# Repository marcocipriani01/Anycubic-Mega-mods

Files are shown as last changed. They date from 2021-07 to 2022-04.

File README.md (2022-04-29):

# Anycubic Mega S mods

This is a collection of mods of the Anycubic Mega S 3D printer. Feel free to experiment with them!

## Copyright notice

This collection contains 3D models and configuration files made by different people (all released without license), and further modified by Marco Cipriani (@marcocipriani01). If you are the original author of one the models, and wish to remove it from this repository, feel free to open a GitHub issue to get in touch. I'm releasing all these modified files under the terms of the **GNU General Public License**, version 3.0. Modifying any of these 3D models requires you to publish them again, under the terms of the same license, and give credits to the original authors. In any way, shall the authors of these files be considered responsible for damages occurred to your 3D printer.

### Credits

- [Anycubic i3 Mega X carriage and Hemera mod](https://www.thingiverse.com/thing:4238185) by Sergiu-I
- ["Filler" filament spool holder](https://www.thingiverse.com/thing:3020026) by HugoHuge
- [BLShield](https://www.thingiverse.com/thing:3419174) by PrinterMods
- [Klipper configuration](https://github.com/widapro/3d-printers) by widapro
- [Customizable fan cover](https://www.thingiverse.com/thing:2802474) by mightynozzle
- [Anycubic I3 Mega feet](https://www.thingiverse.com/thing:3480829/files) by Alexis Rodriguez
- [Anycubic I3 Mega Hot Bed Handle](https://www.thingiverse.com/thing:3217199/files) by Andy Baxter
- [AnyCubic i3 Mega LCD Bezel](https://www.thingiverse.com/thing:2920401/files) by Rui Carneiro

## Other resources

- [Marlin 2.0.x for the Anycubic Mega](https://github.com/knutwurst/Marlin-2-0-x-Anycubic-i3-MEGA-S) by Oliver Köster
- [TMC2209 installation guide](https://github.com/knutwurst/Marlin-2-0-x-Anycubic-i3-MEGA-S/wiki/Swap-stepper-motor-driver-for-TMC2xxx)
- [BLTouch wiring](https://github.com/knutwurst/Marlin-2-0-x-Anycubic-i3-MEGA-S/wiki/BLTouch-Installation-(english))
- [Klipper](https://www.klipper3d.org/) by KevinOConnor
- [Klipper Installation And Update Helper](https://github.com/th33xitus/kiauh) by th33xitus
- [Fluidd web interface for Klipper](https://github.com/cadriel/fluidd) by Craig Bassett
- [Moonraker API Web Server for Klipper](https://github.com/Arksine/moonraker) by Eric Callahan

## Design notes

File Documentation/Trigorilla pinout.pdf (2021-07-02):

### Servo Ports (1)

5V | 5V | 5V | 5V | 5V

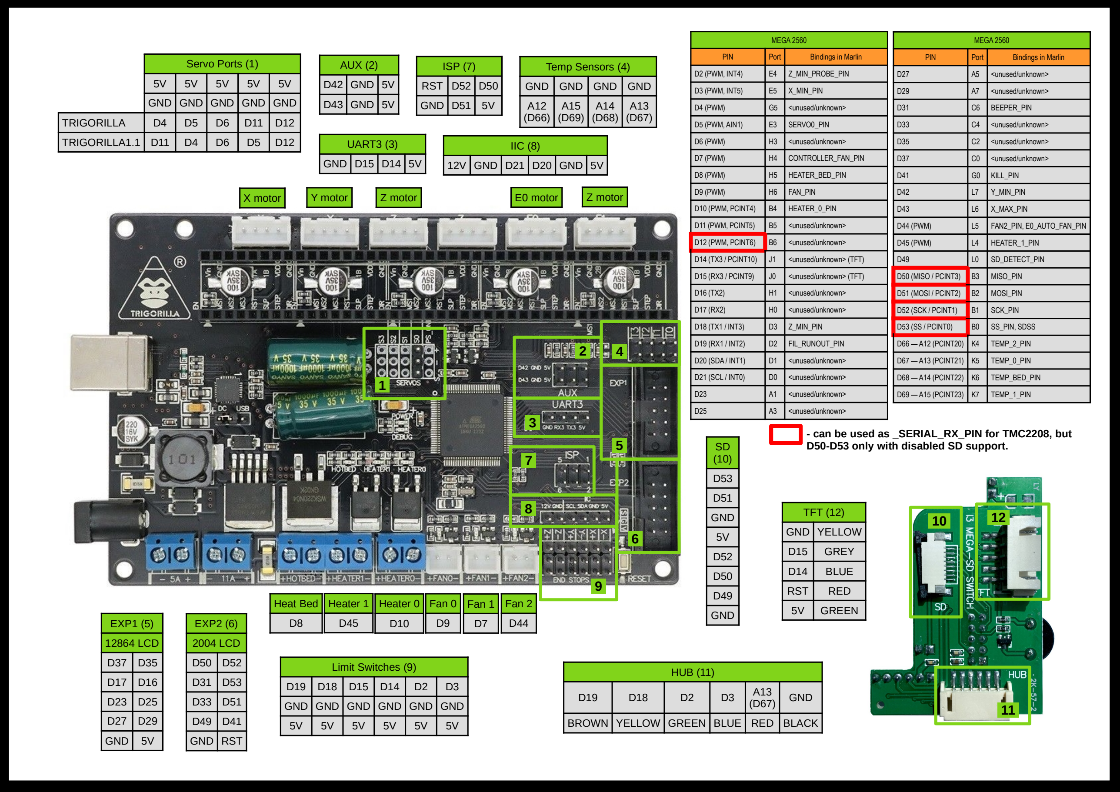
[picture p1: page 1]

| GND | GND | GND | GND | GND
TRIGORILLA | D4 | D5 | D6 | D11 | D12
TRIGORILLA1.1 | D11 | D4 | D6 | D5 | D12

### Temp Sensors (4)

GND | GND | GND | GND
A12
(D66)

A15
(D69)

A14
(D68)

A13
(D67)

### AUX (2)

D42 | GND | 5V
D43 | GND | 5V

### EXP1 (5)

### 12864 LCD

D37 | D35
D17 | D16
D23 | D25
D27 | D29
GND | 5V

MEGA 2560

PIN | Port | Bindings in Marlin
D2 (PWM, INT4) | E4 | Z_MIN_PROBE_PIN
D3 (PWM, INT5) | E5 | X_MIN_PIN
D4 (PWM) | G5 | <unused/unknown>
D5 (PWM, AIN1) | E3 | SERVO0_PIN
D6 (PWM) | H3 | <unused/unknown>
D7 (PWM) | H4 | CONTROLLER_FAN_PIN
D8 (PWM) | H5 | HEATER_BED_PIN
D9 (PWM) | H6 | FAN_PIN
D10 (PWM, PCINT4) | B4 | HEATER_0_PIN
D11 (PWM, PCINT5) | B5 | <unused/unknown>
D12 (PWM, PCINT6) | B6 | <unused/unknown>
D14 (TX3 / PCINT10) | J1 | <unused/unknown> (TFT)
D15 (RX3 / PCINT9) | J0 | <unused/unknown> (TFT)
D16 (TX2) | H1 | <unused/unknown>
D17 (RX2) | H0 | <unused/unknown>
D18 (TX1 / INT3) | D3 | Z_MIN_PIN
D19 (RX1 / INT2) | D2 | FIL_RUNOUT_PIN
D20 (SDA / INT1) | D1 | <unused/unknown>
D21 (SCL / INT0) | D0 | <unused/unknown>
D23 | A1 | <unused/unknown>
D25 | A3 | <unused/unknown>

### IIC (8)

12V | GND | D21 | D20 | GND | 5V

### UART3 (3)

GND | D15 | D14 | 5V

### EXP2 (6)

### 2004 LCD

D50 | D52
D31 | D53
D33 | D51
D49 | D41
GND | RST

### Limit Switches (9)

D19 | D18 | D15 | D14 | D2 | D3
GND | GND | GND | GND | GND | GND
5V | 5V | 5V | 5V | 5V | 5V

### Heat Bed

D8

### Heater 0

D10

### Heater 1

D45

### Fan 0

D9

### Fan 2

D44

### Fan 1

D7

X motor | Y motor | Z motor | E0 motor | Z motor

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
### ISP (7)

RST | D52 | D50
GND | D51 | 5V

MEGA 2560

PIN | Port | Bindings in Marlin
D27 | A5 | <unused/unknown>
D29 | A7 | <unused/unknown>
D31 | C6 | BEEPER_PIN
D33 | C4 | <unused/unknown>
D35 | C2 | <unused/unknown>
D37 | C0 | <unused/unknown>
D41 | G0 | KILL_PIN
D42 | L7 | Y_MIN_PIN
D43 | L6 | X_MAX_PIN
D44 (PWM) | L5 | FAN2_PIN, E0_AUTO_FAN_PIN
D45 (PWM) | L4 | HEATER_1_PIN
D49 | L0 | SD_DETECT_PIN
D50 (MISO / PCINT3) | B3 | MISO_PIN
D51 (MOSI / PCINT2) | B2 | MOSI_PIN
D52 (SCK / PCINT1) | B1 | SCK_PIN
D53 (SS / PCINT0) | B0 | SS_PIN, SDSS
D66 — A12 (PCINT20) | K4 | TEMP_2_PIN
D67 — A13 (PCINT21) | K5 | TEMP_0_PIN
D68 — A14 (PCINT22) | K6 | TEMP_BED_PIN
D69 — A15 (PCINT23) | K7 | TEMP_1_PIN

SD
(10)
D53
D51

### GND

5V
D52
D50
D49

### GND

### HUB (11)

D19 | D18 | D2 | D3 | A13 (D67) | GND
BROWN | YELLOW | GREEN | BLUE | RED | BLACK

10 12

11

### - can be used as _SERIAL_RX_PIN for TMC2208, but

D50-D53 only with disabled SD support.

### TFT (12)

GND | YELLOW
D15 | GREY
D14 | BLUE
RST | RED
5V | GREEN

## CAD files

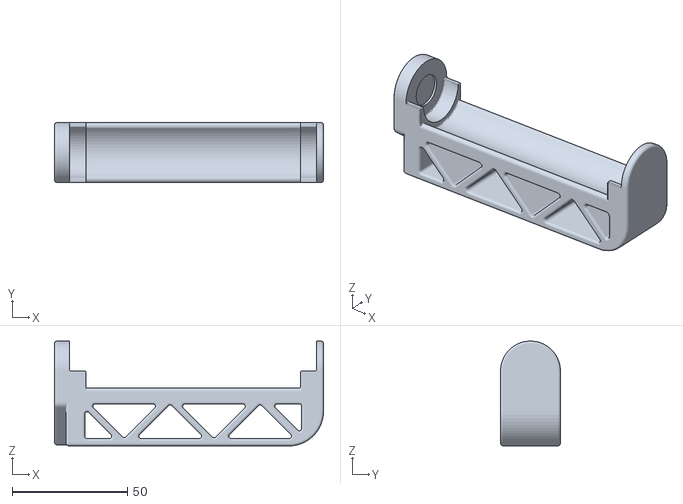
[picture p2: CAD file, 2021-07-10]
Filament holder with bearings/Filament holder with 608 bearings - main body.stl
116.8 x 26.0 x 45.5

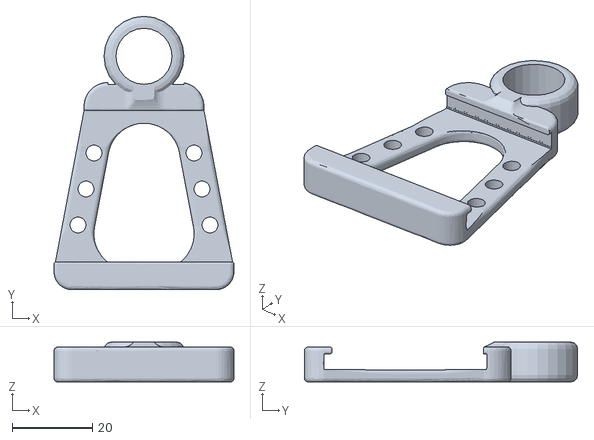
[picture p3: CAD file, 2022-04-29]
Bed handle/Bed handle.stl
45.0 x 68.4 x 10.00

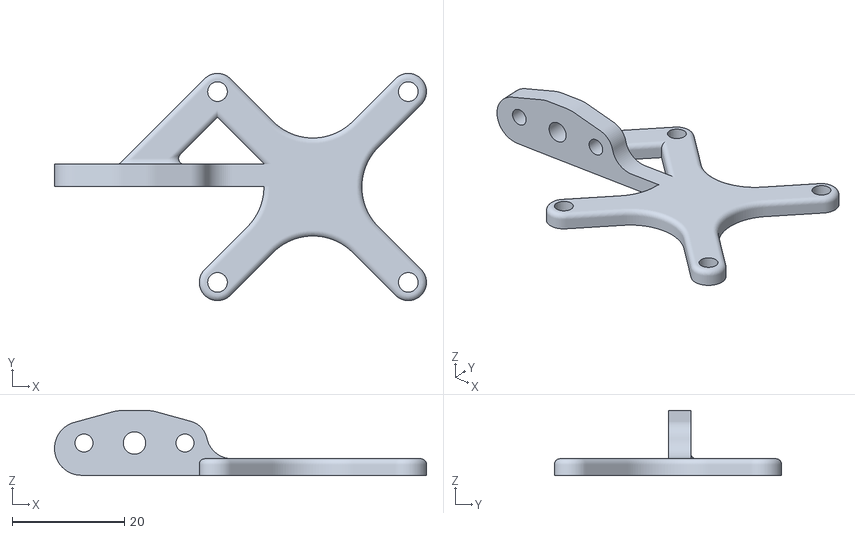
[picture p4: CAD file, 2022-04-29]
BLTouch/Hemera support.stl
66.3 x 40.5 x 11.6

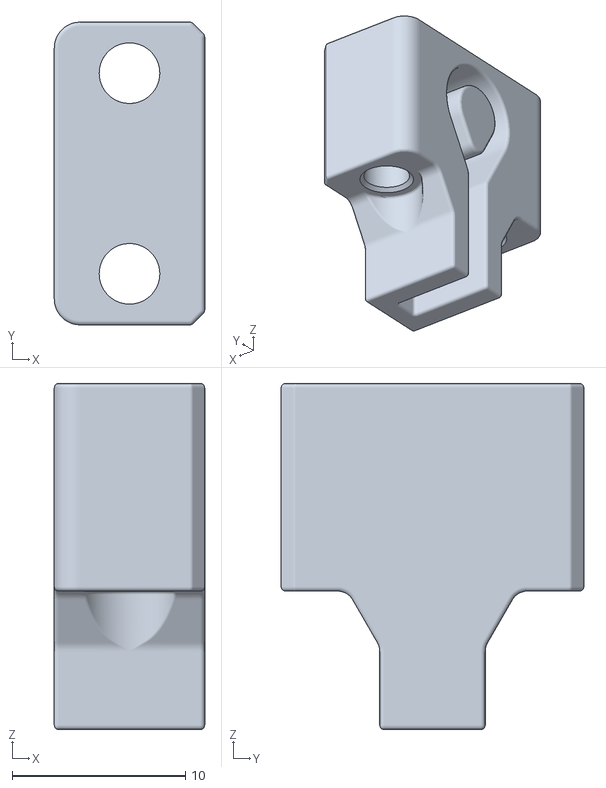
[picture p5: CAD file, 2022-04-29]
E3D Hemera and TriangleLab Matrix X-carriage/Belt tensioner - 2x.stl
8.70 x 17.5 x 20.0

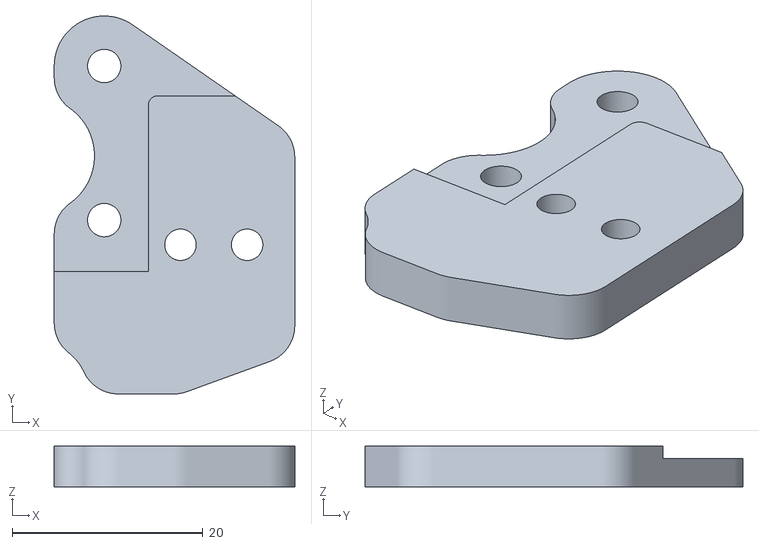
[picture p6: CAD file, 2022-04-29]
Improved X axis/Left endstop support.stl
25.2 x 39.7 x 4.30

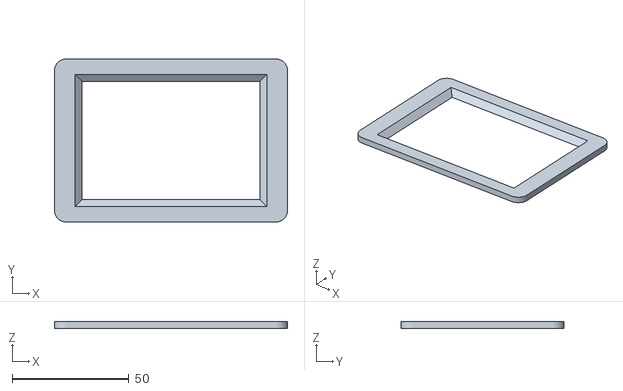
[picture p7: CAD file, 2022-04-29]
LCD mods/LCD bezel.stl
100.0 x 70.0 x 3.00

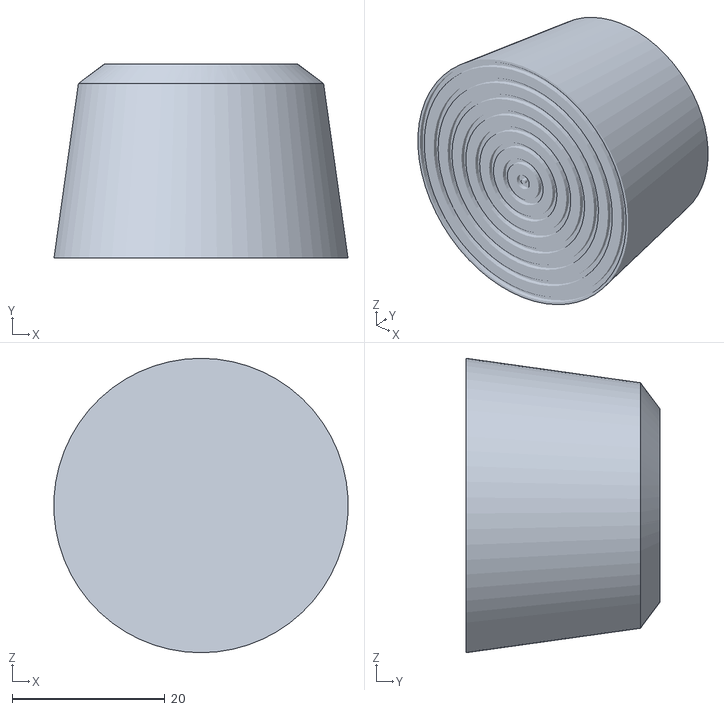
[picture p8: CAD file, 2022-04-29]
TPU feet/TPU feet.stl
38.6 x 25.4 x 38.6

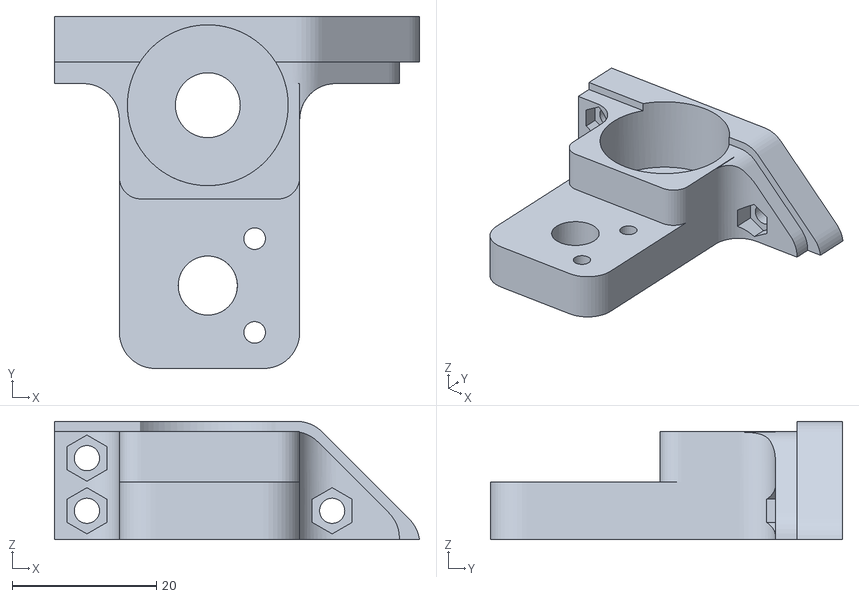
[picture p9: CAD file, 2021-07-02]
Z axis stabilizer/Z axis stabilizer - right.stl
50.6 x 48.8 x 16.4

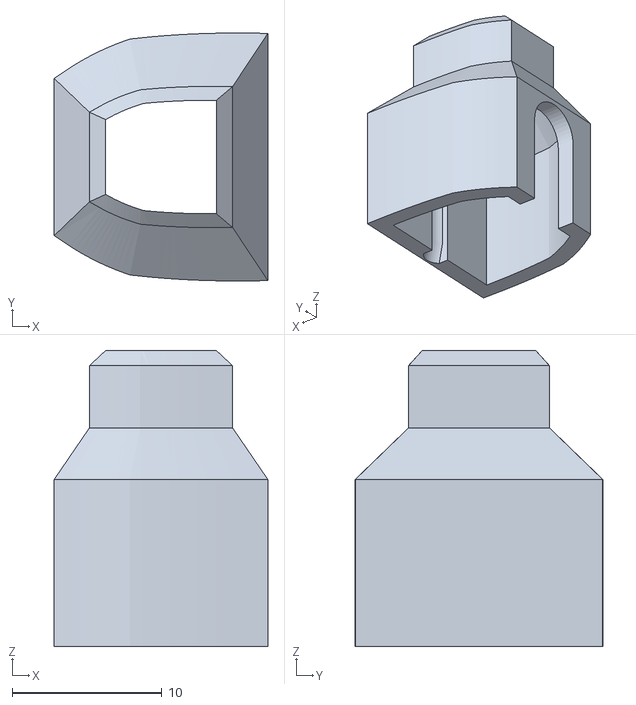
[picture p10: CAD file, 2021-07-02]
BLTouch/BL-shield.stl
14.3 x 16.6 x 19.8

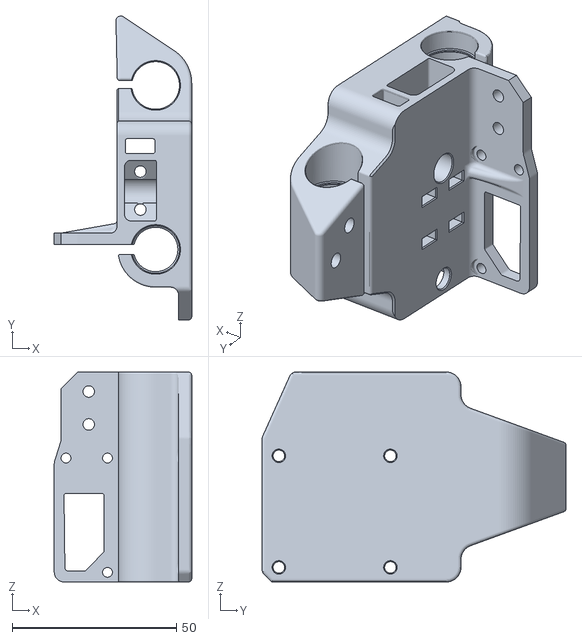
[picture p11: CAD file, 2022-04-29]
E3D Hemera and TriangleLab Matrix X-carriage/X carriage for E3D Hemera and TriangleLab Matrix.stl
41.9 x 92.7 x 64.0

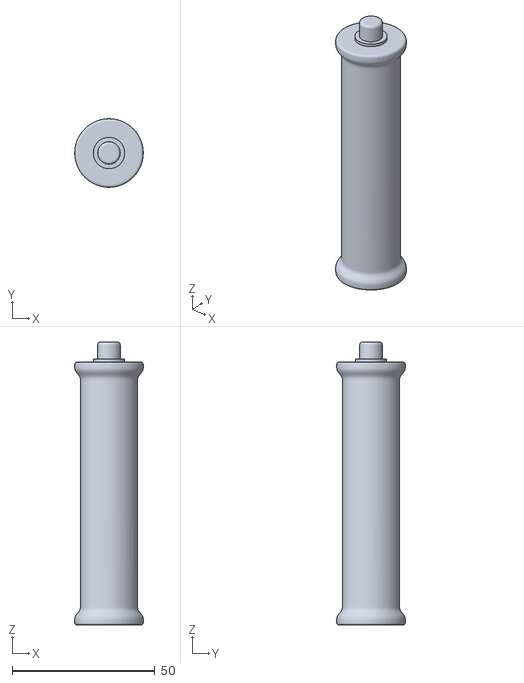
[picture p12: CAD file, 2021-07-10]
Filament holder with bearings/Filament holder with 608 bearings - cylinder.stl
24.0 x 24.0 x 99.0

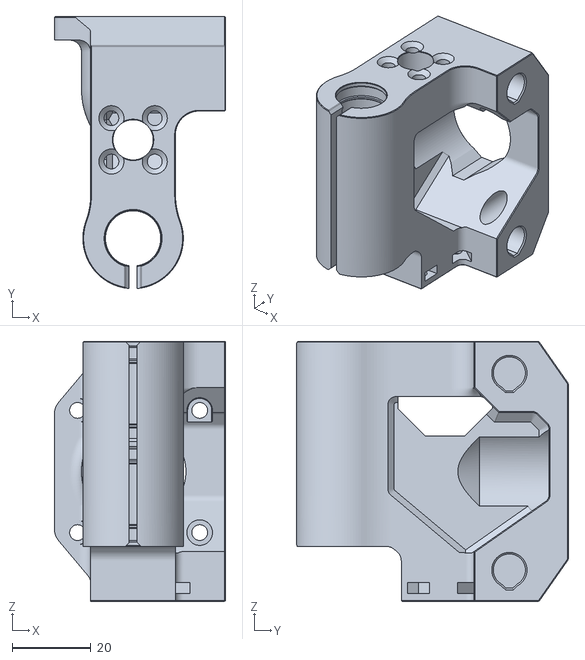
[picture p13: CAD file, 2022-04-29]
Improved X axis/X axis slider - left.stl
43.5 x 69.0 x 66.0

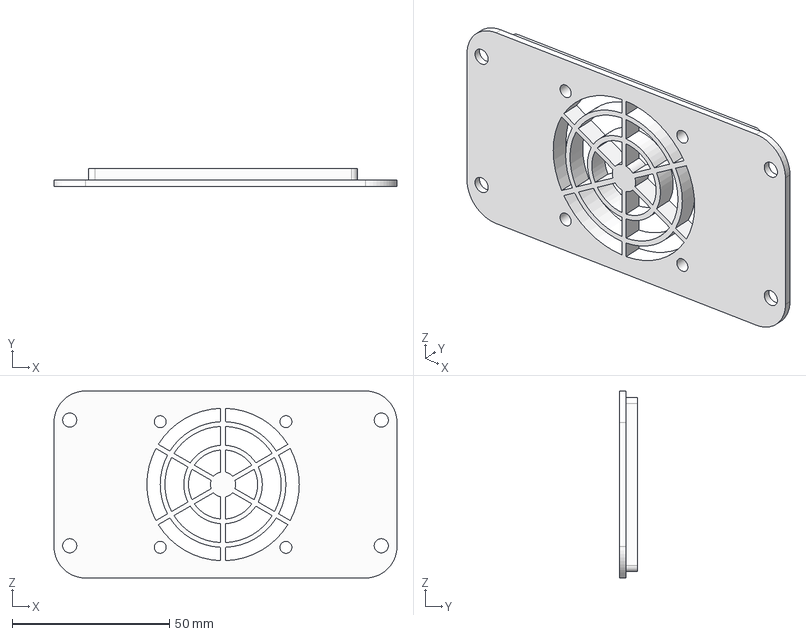
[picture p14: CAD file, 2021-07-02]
LCD mods/LCD cooling fan mod.step
109.2 x 5.60 x 59.5 mm

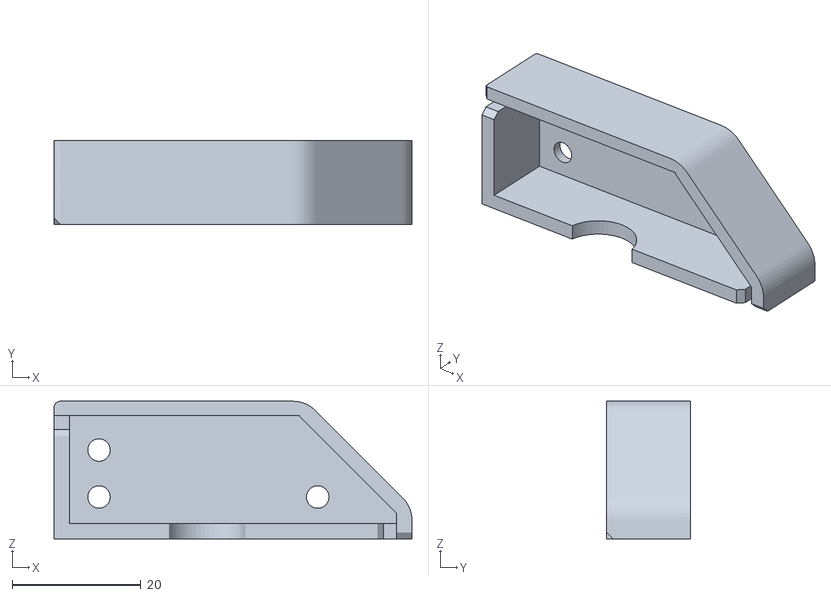
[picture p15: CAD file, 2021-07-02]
Z axis stabilizer/Z axis stabilizer cover - right.stl
55.7 x 13.0 x 21.4

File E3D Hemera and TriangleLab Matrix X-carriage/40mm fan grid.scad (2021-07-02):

/*
 * Customizable Fan Cover - https://www.thingiverse.com/thing:2802474
 * by Dennis Hofmann - https://www.thingiverse.com/mightynozzle/about
 * created 2018-02-22
 * updated 2018-03-27
 * version v1.2
 *
 * Changelog
 * --------------
 * v1.2:
 *      - better quality of rounded corners and crosshair pattern
 * v1.1:
 *      - added support line option for crosshair and square pattern
 * v1.0:
 *      - final design
 * --------------
 *
 * This work is licensed under the Creative Commons - Attribution - Non-Commercial - ShareAlike license.
 * https://creativecommons.org/licenses/by-nc-sa/3.0/
 */


 // Parameter Section //
//-------------------//

/* [Global Settings] */

// Choose between presets of known and common fan sizes.
fan_preset = "custom"; //[25:25mm,30:30mm,40:40mm,50:50mm,60:60mm,70:70mm,80:80mm,92:92mm,120:120mm,140:140mm,custom:Custom Fan Settings]

// If you want save to save about 40% filament and about 20% printing time, you can choose the reduced frame option.
frame_option = "reduced"; //[full,reduced]

// Minimum Border Size. I recommend to use two/four/six... times of your line width setting of your slicer. Simplify3D uses 0.48mm line width by default if you are using a 0.4mm nozzle. Cura uses 0.4mm line width.
min_border_size_in_millimeter = 0.52*3;

// Choose between a grill pattern
grill_pattern = "honeycomb"; //[honeycomb,grid,line,triangle,crosshair,square,dot,aperture]

// Set the angle of the pattern around the center of the cover.
grill_pattern_rotation = 0; //[0:5:360]

// Size of the pattern lines. I recommend to use two/four/six... times of your line width setting of your slicer. Simplify3D uses 0.48mm line width by default if you are using a 0.4mm nozzle. Cura uses 0.4mm line width.
line_size_in_millimter = 0.52*2; //[0.3:0.02:4]

// Space between two lines of your pattern. If you choose aperture pattern, this value set the size of the center octagon.
line_space_in_millimeter = 6; //[1:0.1:50]

// If you need countersunk holes, you can activate it here. Bottom = first layer. Top = last layer. 
screw_hole_chamfer = "no"; //[no,top,bottom,top_and_bottom]

// Activate or deactivate rounded corners. The radius will be automatically calculated.
rounded_corners = "yes"; //[yes,no]

// number of straight lines supporting the crosshair or square pattern.
number_of_support_lines = 2;  //[1:1:36]

/* [Custom Fan Settings] */

// Cover size. E.g. 80 for a 80mm Fan
cover_size_in_millimeter = 40;

// E.g. 2.9 for M2.5, 3.3 for M3, 4.4 for M4
screw_hole_diameter_in_millimeter = 3.6;

// 25mm fan: 20 | 30mm fan: 24 | 40mm fan: 32 | 50mm fan: 40 | 60mm fan: 50 | 70mm fan: 61.5 | 80mm fan: 71.5 | 92mm fan: 82.5 | 120mm fan: 105 | 140mm fan: 126 
screw_hole_distance_in_millimeter = 32;

// Height of the outer frame of the cover
cover_height_in_millimeter = 2;

// Height of the pattern inside the cover frame
grill_pattern_height_in_millimeter = 1;

/* [Hidden] */
min_border_size = min_border_size_in_millimeter;
line_size = line_size_in_millimter;
line_space = line_space_in_millimeter;

 // Program Section //
//-----------------//

if(fan_preset == "25") {
    fan_cover(cover_size = 25, screw_hole_dia = 2.9, screw_hole_distance = 20, cover_h = 2, grill_pattern_h = 1);
}
if(fan_preset == "30") {
    fan_cover(cover_size = 30, screw_hole_dia = 3.3, screw_hole_distance = 24, cover_h = 2.5, grill_pattern_h = 1.1);
}
if(fan_preset == "40") {
    fan_cover(cover_size = 40, screw_hole_dia = 3.3, screw_hole_distance = 32, cover_h = 2.7, grill_pattern_h = 1.2);
}
if(fan_preset == "50") {
    fan_cover(cover_size = 50, screw_hole_dia = 4.4, screw_hole_distance = 40, cover_h = 2.9, grill_pattern_h = 1.3);
}
if(fan_preset == "60") {
    fan_cover(cover_size = 60, screw_hole_dia = 4.4, screw_hole_distance = 50, cover_h = 3, grill_pattern_h = 1.3);
}
if(fan_preset == "70") {
    fan_cover(cover_size = 70, screw_hole_dia = 4.4, screw_hole_distance = 61.5, cover_h = 3, grill_pattern_h = 1.4);
}
if(fan_preset == "80") {
    fan_cover(cover_size = 80, screw_hole_dia = 4.4, screw_hole_distance = 71.5, cover_h = 3.2, grill_pattern_h = 1.5);
}
if(fan_preset == "92") {
    fan_cover(cover_size = 92, screw_hole_dia = 4.4, screw_hole_distance = 82.5, cover_h = 3.5, grill_pattern_h = 1.6);
}
if(fan_preset == "120") {
    fan_cover(cover_size = 120, screw_hole_dia = 4.4, screw_hole_distance = 105, cover_h = 4, grill_pattern_h = 1.8);
}
if(fan_preset == "140") {
    fan_cover(cover_size = 140, screw_hole_dia = 4.4, screw_hole_distance = 126, cover_h = 4.5, grill_pattern_h = 2.0);
}
if(fan_preset == "custom") {
    fan_cover(cover_size = cover_size_in_millimeter, screw_hole_dia = screw_hole_diameter_in_millimeter, screw_hole_distance = screw_hole_distance_in_millimeter, cover_h = cover_height_in_millimeter, grill_pattern_h = grill_pattern_height_in_millimeter);
}


 // Module Section //
//----------------//

module fan_cover(cover_size, screw_hole_dia, screw_hole_distance, cover_h, grill_pattern_h) {
    corner_size = cover_size - screw_hole_distance;
    corner_r = rounded_corners == "yes" ? corner_size / 2 : 0;
    screw_pos = (cover_size - corner_size) / 2;
    color("DodgerBlue") difference() {
        union() {
            linear_extrude(height = cover_h, convexity = 20) {
                difference() {
                    offset(r=corner_r, $fn = ceil(corner_r * 8)) {
                        offset(r=-corner_r) {
                            square([cover_size, cover_size], center = true);
                        }
                    }
                    if(frame_option == "reduced") {
                        offset(r=corner_r, $fn = ceil(corner_r * 8)) {
                            offset(r=-corner_r) {
                                square([cover_size - min_border_size*2, cover_size - min_border_size*2], center = true);
                            }
                        }
                    }
                    if(frame_option == "full") {
                        circle(d = cover_size - min_border_size * 2, $fn = cover_size);
                    }
                } 
                if(frame_option == "reduced") {
                    for(y = [-1:2:1]) {
                        for(x = [-1:2:1]) {
                            translate([screw_pos * x, screw_pos * y, -2]) {
                                circle(d = corner_size, $fn = ceil(corner_r * 8));
                            }
                        }
                    }
                }
            }
            linear_extrude(height = grill_pattern_h, convexity = 20) {
                intersection() {
                    offset(r=corner_r, $fn = ceil(corner_r * 8)) {
                        offset(r=-corner_r) {
                            square([cover_size, cover_size], center = true);
                        }
                    }
                    rotate(grill_pattern_rotation) {
                        if(grill_pattern == "honeycomb") {
                            honeycomb_pattern(cover_size, line_size, line_space);
                        }
                        if(grill_pattern == "grid") {
                            grid_pattern(cover_size, line_size, line_space);
                        }
                        if(grill_pattern == "line") {
                            line_pattern(cover_size, line_size, line_space);
                        }
                        if(grill_pattern == "triangle") {
                            triangle_pattern(cover_size, line_size, line_space);
                        }
                        if(grill_pattern == "crosshair") {
                            crosshair_pattern(cover_size, line_size, line_space);
                        }
                        if(grill_pattern == "square") {
                            square_pattern(cover_size, line_size, line_space);
                        }
                        if(grill_pattern == "dot") {
                            dot_pattern(cover_size, line_size, line_space);
                        }
                        if(grill_pattern == "aperture") {
                            aperture_pattern(cover_size, line_size, line_space);
                        }
                        
                    }
                }
            }
        }
        for(y = [-1:2:1]) {
            for(x = [-1:2:1]) {
                translate([screw_pos * x, screw_pos * y, -2]) {
                    screw_hole(cover_h, screw_hole_dia);
                }
            }
        }
    }
}
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

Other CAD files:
E3D Hemera and TriangleLab Matrix X-carriage/40mm fan grid.stl
Filament holder with bearings/Filament holder with 608 bearings.step
Improved X axis/Pulley slider.stl
Z axis stabilizer/Z axis stabilizer - left.stl
E3D Hemera and TriangleLab Matrix X-carriage/Cable chain support.stl
E3D Hemera and TriangleLab Matrix X-carriage/Cooling fan duct.stl
Filament holder with bearings/Filament holder with 608 bearings - bearing pin.stl
Improved X axis/X axis slider - right.stl
LCD mods/LCD cooling fan mod.f3d
LCD mods/LCD cooling fan mod.stl
Z axis stabilizer/Z axis stabilizer cover - left.stl

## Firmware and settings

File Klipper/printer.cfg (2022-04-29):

# 
# Klipper configuration file for Anycubic i3 MEGA S
#
# This config file contains settings of all printer pins (steppers, sensors) for the Anycubic i3 Mega S. 
# Klipper firmware should be compiled for the atmega2560
#
# Config file includes
#  - Mesh bed leveling: BLtouch (or 3DTouch sensor from Triangelab)
#  - Manual meshed bed leveling (commented out)
#  - 'virtual_sdcard' for fast printing without gaps
#  - Buzzer through M300 gcode
#  - Pause/Resume through M600 for filament change
#
# Note: when using BLTouch, home position is determined by 3DTouch. Z limit switches are not used.
#
# The latest version of the config reference is also available online at:
# https://www.klipper3d.org/Config_Reference.html
#
# Based on the work by Barys (@widapro) on GitHub: https://github.com/widapro/3d-printers
# And further improved by Marco Cipriani (@marcocipriani01)


[mcu]
## Change to match your serial port
serial: /dev/serial/by-id/usb-Silicon_Labs_CP2102N_USB_to_UART_Bridge_Controller_d061fb26bb6ae811b9b298fc9c710798-if00-port0
[temperature_sensor raspberry_pi]
sensor_type: temperature_host
min_temp: 10
max_temp: 100

[include xyz.cfg]
[include hacks.cfg]
[include power.cfg]
[include macros.cfg]
[include tuning.cfg]

[extruder]
step_pin: ar26
dir_pin: ar28
enable_pin: !ar24
#control: pid
## TriangleLab Matrix extruder
#rotation_distance: 9.54084675
rotation_distance: 9.493142516
microsteps: 16
full_steps_per_rotation: 200
nozzle_diameter: 0.5
filament_diameter: 1.75
heater_pin: ar10
## Uncomment below for the PT1000 temperature sensor (upgrade)
sensor_type: PT1000
## Uncomment below for the default Anycubic Mega temperature sensor
#sensor_type: ATC Semitec 104GT-2
sensor_pin: analog13
min_temp: 0
max_temp: 300
max_extrude_only_distance: 500.0
smooth_time: 1
min_extrude_temp: 180
## Pressure advance needs to be calibrated
pressure_advance: 0.0375
max_extrude_cross_section: 150

[heater_bed]
heater_pin: ar8
sensor_type: EPCOS 100K B57560G104F
sensor_pin: analog14
min_temp: 0
max_temp: 110
smooth_time: 1
#control: pid

[fan]
pin: ar9
[controller_fan mainboard_fan]
pin: ar7
stepper: stepper_x
idle_timeout: 30
[heater_fan extruder_fan]
pin: ar44
heater: extruder
heater_temp: 50

[output_pin buzzer_pin]
pin: ar31
pwm: True
value: 0
shutdown_value: 0
cycle_time: 0.001
scale: 1000

#*# <---------------------- SAVE_CONFIG ---------------------->
#*# DO NOT EDIT THIS BLOCK OR BELOW. The contents are auto-generated.
#*#
#*# [heater_bed]
#*# pid_kp = 70.661
#*# pid_ki = 2.692
#*# pid_kd = 463.715
#*# control = pid
#*#
#*# [extruder]
#*# pid_kp = 22.723
#*# pid_ki = 0.828
#*# pid_kd = 155.935
#*# control = pid
#*#
#*# [bed_mesh default]
#*# version = 1
#*# points =
#*# 	  -0.039471, 0.090529, 0.175529, 0.118029, 0.010529
#*# 	  0.020529, 0.040529, 0.083029, 0.065529, 0.105529
#*# 	  0.118029, 0.128029, 0.165529, 0.210529, 0.265529
#*# 	  0.195529, 0.265529, 0.303029, 0.368029, 0.450529
#*# 	  0.295529, 0.465529, 0.590529, 0.648029, 0.638029
#*# tension = 0.2
#*# min_x = 20.0
#*# algo = bicubic
#*# y_count = 5
#*# mesh_y_pps = 2
#*# min_y = 10.0
#*# x_count = 5
#*# max_y = 180.0
#*# mesh_x_pps = 2
#*# max_x = 190.0

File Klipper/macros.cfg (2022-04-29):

# Gcode macros

[gcode_macro START_GCODE]
variable_purge: 1
gcode:
    {% set bed_temp = params.BED_TEMP|float %}
    {% set extruder_temp = params.EXTRUDER_TEMP|float %}
    G21                                          ; Metric values
    G90                                          ; Absolute positioning
    M82                                          ; Set extruder to absolute mode
    M140 S{bed_temp}                             ; Start heating the bed
    M104 S{extruder_temp}                        ; start heating the hot end
    {% if printer.extruder.temperature < extruder_temp - 10 %}
        M109 S{extruder_temp}                    ; Wait for hotend
    {% endif %}
    {% if bed_temp != 0 and printer.heater_bed.temperature < bed_temp - 10 %}
        M190 S{bed_temp}                         ; Wait for bed
    {% endif %}
    SET_VELOCITY_LIMIT VELOCITY=200 ACCEL=1300 ACCEL_TO_DECEL=800 SQUARE_CORNER_VELOCITY=5
    {% if printer.toolhead.homed_axes != "xyz" %}
        G28                                      ; Home XYZ
    {% endif %}
    BED_MESH_PROFILE LOAD=default
    {% if purge == 1 %}
        G0 X25 Y1 Z0.2 F1500
        G92 E0                                   ; Zero the extruded lengt
        G1 X60 E20 F500                          ; Extrude 25mm of filament in a 5cm line.
        G92 E0                                   ; Zero the extruded length again
        G1 X90 F4000                             ; Quickly wipe away from the filament line
    {% else %}
        G1 E15 F500
        M300 S299 P200
        M300 S299 P200
        M300 S299 P200
        G4 P5000
        G92 E0
    {% endif %}

[gcode_macro END_GCODE]
variable_nonstop: 0
variable_shutdown: 0
gcode:
    G91                                           ; Relative positioning
    G1 Z+20 E-10 F1700                            ; Move Z up and retract
    M107                                          ; Fan off
    G90                                           ; Absolute positioning
    G1 X20 Y180 F1500                             ; Move bed forward
    M300 S299 P200
    M300 S299 P200
    M300 S299 P200
    M300 S299 P200
    M300 S299 P200
    {% if nonstop == 0 %}
        M84                                       ; Disable stepper motors
        BED_MESH_CLEAR
        TURN_OFF_HEATERS
    {% else %}
        M300 S299 P200
        M300 S299 P200
        M300 S299 P200
        M300 S299 P200
    {% endif %}
    {% if shutdown == 1 %}
        UPDATE_DELAYED_GCODE ID=SHUTDOWN_PRINTER_CHECK DURATION=10
    {% endif %}

[gcode_macro PAUSE]
rename_existing: BASE_PAUSE
# change this if you need more or less extrusion
variable_extrude: 1.0
gcode:
    ##### Read E from pause macro #####
    {% set E = printer["gcode_macro PAUSE"].extrude|float %}
    ##### Set park positon for x and y #####
    # Default is your max posion from your printer.cfg
    {% set x_park = printer.toolhead.axis_maximum.x|float - 5.0 %}
    {% set y_park = printer.toolhead.axis_maximum.y|float - 5.0 %}
    ##### Calculate save lift position #####
    {% set max_z = printer.toolhead.axis_maximum.z|float %}
    {% set act_z = printer.toolhead.position.z|float %}
    {% if act_z < (max_z - 2.0) %}
        {% set z_safe = 2.0 %}
    {% else %}
        {% set z_safe = max_z - act_z %}
    {% endif %}
    ##### End of definitions #####
    SAVE_GCODE_STATE NAME=PAUSE_state
    BASE_PAUSE
    G91
    G1 E-{E} F2100
    G1 Z{z_safe} F900
    G90
    G1 X{x_park} Y{y_park} F6000

[gcode_macro RESUME]
rename_existing: BASE_RESUME
gcode:
  ##### Read E from pause macro #####
  {% set E = printer["gcode_macro PAUSE"].extrude|float %}
  ##### End of definitions #####
  G91
  G1 E{E} F2100
  RESTORE_GCODE_STATE NAME=PAUSE_state
  BASE_RESUME

[gcode_macro CANCEL_PRINT]
rename_existing: BASE_CANCEL_PRINT
gcode:
    # Reset Speed factor override percentage to default (100%)
    M220 S100
    # Reset Extrude factor override percentage to default (100%)
    M221 S100
    M107
    {% if printer.toolhead.homed_axes == "xyz" %}
        G91
        {% if printer.extruder.temperature >= 180 %}
            G1 Z+20 E-6 F1500
        {% else %}
            G1 Z+20 F1500
        {% endif %}
        G90
        G1 X20 Y180 F1500
    {% elif printer.extruder.temperature >= 180 %}
        G1 E-6 F1500
    {% endif %}
    M84
    TURN_OFF_HEATERS
    CLEAR_PAUSE
    SDCARD_RESET_FILE
    BASE_CANCEL_PRINT

[gcode_macro CANCEL_PRINT_KEEP_HEAT]
gcode:
    M107
    {% if printer.toolhead.homed_axes == "xyz" %}
        G91
        {% if printer.extruder.temperature >= 180 %}
            G1 Z+20 E-6 F1500
        {% else %}
            G1 Z+20 F1500
        {% endif %}
        G90
        G1 X20 Y180 F1500
    {% elif printer.extruder.temperature >= 180 %}
        G1 E-6 F1500
    {% endif %}
    CLEAR_PAUSE
    SDCARD_RESET_FILE
    BASE_CANCEL_PRINT

[gcode_macro REMOVE_FILAMENT]
gcode:
    M109 S220
    G91
    G1 E-100 F1000
    G90
    M84
    TURN_OFF_HEATERS
    M300 S299 P200
    M300 S299 P200
    M300 S299 P200
    M300 S299 P200
    M300 S299 P200

[gcode_macro ALL_OFF]
gcode:
    M107
    M84
    TURN_OFF_HEATERS

[gcode_macro M600]
gcode:
    {% set x = params.X|default(190)|float %}
    {% set y = params.Y|default(100)|float %}
    {% set z = params.Z|default(100)|float %}
    SAVE_GCODE_STATE NAME=M600_state
    PAUSE
    G91
    G1 E-.8 F2700
    G1 Z{z}
    G90
    G1 X{x} Y{y} F3000
    G91
    #G1 E-150 F1000
    M300 S299 P200
    M300 S299 P200
    M300 S299 P200
    M300 S299 P200
    M300 S299 P200
    RESTORE_GCODE_STATE NAME=M600_state

[gcode_macro SET_NONSTOP_ON]
gcode:
    SET_GCODE_VARIABLE MACRO="END_GCODE" VARIABLE=shutdown VALUE=0
    SET_GCODE_VARIABLE MACRO="END_GCODE" VARIABLE=nonstop VALUE=1

[gcode_macro SET_NONSTOP_OFF]
gcode:
    SET_GCODE_VARIABLE MACRO="END_GCODE" VARIABLE=nonstop VALUE=0

[gcode_macro SET_SHUTDOWN_ON]
gcode:
    SET_GCODE_VARIABLE MACRO="END_GCODE" VARIABLE=nonstop VALUE=0
    SET_GCODE_VARIABLE MACRO="END_GCODE" VARIABLE=shutdown VALUE=1

[gcode_macro SET_SHUTDOWN_OFF]
gcode:
    SET_GCODE_VARIABLE MACRO="END_GCODE" VARIABLE=shutdown VALUE=0

[gcode_macro SET_PURGE_ON]
gcode:
    SET_GCODE_VARIABLE MACRO="START_GCODE" VARIABLE=purge VALUE=1

[gcode_macro SET_PURGE_OFF]
gcode:
    SET_GCODE_VARIABLE MACRO="START_GCODE" VARIABLE=purge VALUE=0
